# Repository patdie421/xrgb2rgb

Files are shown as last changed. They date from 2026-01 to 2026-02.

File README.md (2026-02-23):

# Goal of this converter
This card convert TTL RGB (xRGB / TTLLS / ... from some Apple IIe cards or Apple ///) to "standard" RGB. Color are not exactly the same as the Apple IIe color palette but it's usable !  
It was designed for my Taxan Model 410-80 card to chaine it with a PCT Colorswitch (see https://github.com/patdie421/pct-connectors-rebuild/blob/main/README.md).  
It should work for other kind of card who can be connected to Taxan RGBvision (mode II), AppleColour (AppleColor) 100 monitor or equivalent.  
The converter is base on the output stage circuit of the Chat Mauve EVE Card (https://mirrors.apple2.org.za/ftp.apple.asimov.net/documentation/hardware/video/Le%20Chat%20Mauve%20-%20Manuel%20de%20re_25cc_2581fe_25cc_2581rence.pdf).  
# Working status
- Apple II GS Color monitor direct connexion: tested, working
- Apple II GS Color monitor via PCT Colorswitch: tested, working
- Scart TV/Monitor: not tester (use at your own risk ... like all usual :-) )
- Other RGB monitor: can't be tested (but will be done), I have only an Apple II GS monitor ... (give me feedback, please)  
# usefull link
- https://hobbytronics.home.blog/2024/12/21/apple-iigs-rgb-monitor-scart-cable/
- https://apple3.org/Documents/Schematics/ConsortiRGB.png
- https://mirrors.apple2.org.za/ftp.apple.asimov.net/documentation/hardware/video/AppleService%20Technical%20Procedures%20-%20AppleColor%20Monitor%20100.pdf

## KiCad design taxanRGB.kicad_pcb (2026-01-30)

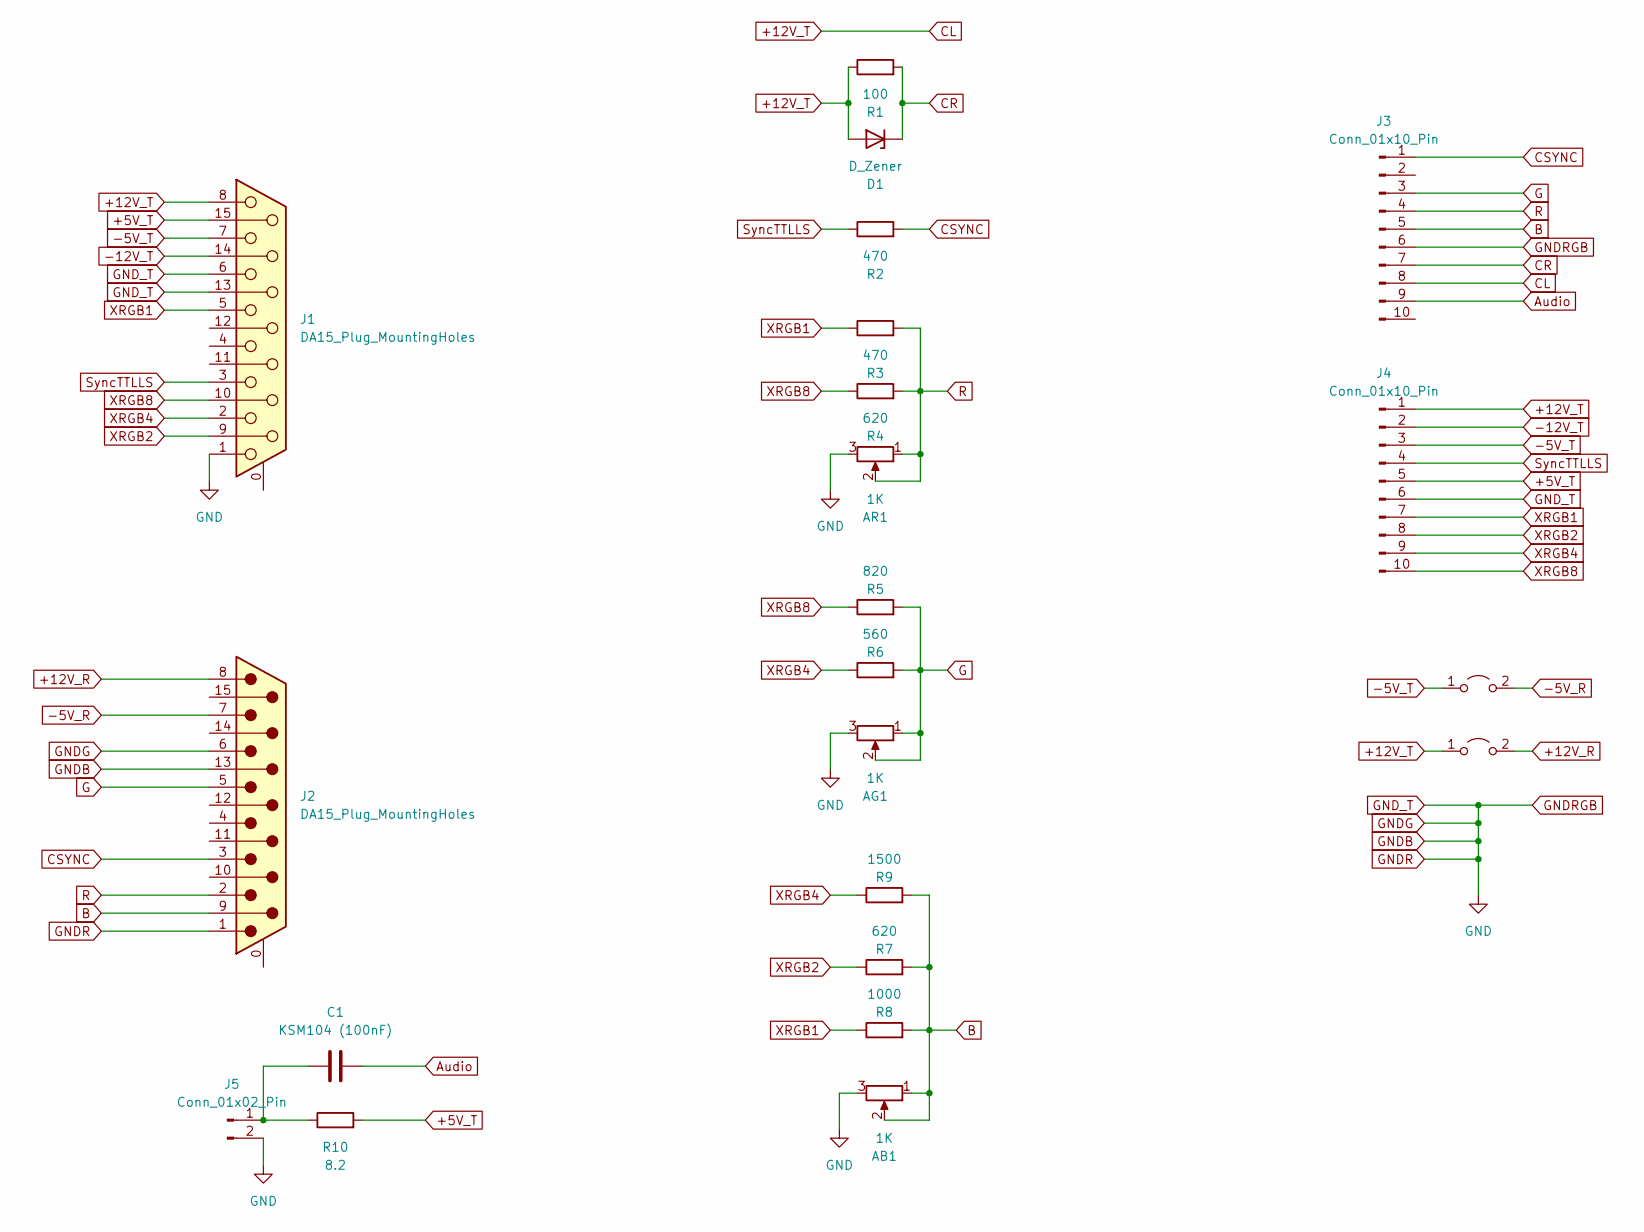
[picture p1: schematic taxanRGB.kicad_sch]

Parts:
AB1: 1K; Potentiometer_Piher_PT-10-V10_Vertical
AG1: 1K; Potentiometer_Piher_PT-10-V10_Vertical
AR1: 1K; Potentiometer_Piher_PT-10-V10_Vertical
C1: KSM104 (100nF); C_Disc_D4.3mm_W1.9mm_P5.00mm
D1: D_Zener; D_DO-34_SOD68_P10.16mm_Horizontal
J1: DA15_Plug_MountingHoles; DSUB-15_Male_EdgeMount_P2.77mm
J2: DA15_Plug_MountingHoles; DSUB-15_Female_EdgeMount_P2.77mm
J3, J4: Conn_01x10_Pin; PinHeader_1x10_P2.54mm_Vertical
J5: Conn_01x02_Pin; PinHeader_1x02_P2.54mm_Vertical
JP1, JP2: Jumper_2_Open; SolderJumper-2_P1.3mm_Open_TrianglePad1.0x1.5mm
R1: 100; R_Axial_DIN0309_L9.0mm_D3.2mm_P12.70mm_Horizontal
R2, R3: 470; R_Axial_DIN0309_L9.0mm_D3.2mm_P12.70mm_Horizontal
R4, R7: 620; R_Axial_DIN0309_L9.0mm_D3.2mm_P12.70mm_Horizontal
R5: 820; R_Axial_DIN0309_L9.0mm_D3.2mm_P12.70mm_Horizontal
R6: 560; R_Axial_DIN0309_L9.0mm_D3.2mm_P12.70mm_Horizontal
R8: 1000; R_Axial_DIN0309_L9.0mm_D3.2mm_P12.70mm_Horizontal
R9: 1500; R_Axial_DIN0309_L9.0mm_D3.2mm_P12.70mm_Horizontal
R10: 8.2; R_Axial_DIN0309_L9.0mm_D3.2mm_P12.70mm_Horizontal

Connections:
+5V_T: J1.15, J4.5, R10.2
+12V_R: J2.8, JP2.2 (B)
+12V_T: D1.2 (A), J1.8, J3.8, J4.1, JP2.1 (A), R1.1
-5V_R: J2.7, JP1.2 (B)
-5V_T: J1.7, J4.3, JP1.1 (A)
-12V_T: J1.14, J4.2
Audio: C1.1, J3.9
B: AB1.1, AB1.2, J2.9, J3.5, R7.2, R8.2, R9.2
CR: D1.1 (K), J3.7, R1.2
CSYNC: J2.3, J3.1, R2.2
G: AG1.1, AG1.2, J2.5, J3.3, R5.2, R6.2
GNDB: AB1.3, AG1.3, AR1.3, J1.1, J1.6, J1.13, J2.1, J2.6, J2.13, J3.6, J4.6, J5.2
unnamed: C1.2, J5.1, R10.1
R: AR1.1, AR1.2, J2.2, J3.4, R3.2, R4.2
SyncTTLLS: J1.3, J4.4, R2.1
XRGB1: J1.5, J4.7, R3.1, R8.1
XRGB2: J1.9, J4.8, R7.1
XRGB4: J1.2, J4.9, R6.1, R9.1
XRGB8: J1.10, J4.10, R4.1, R5.1

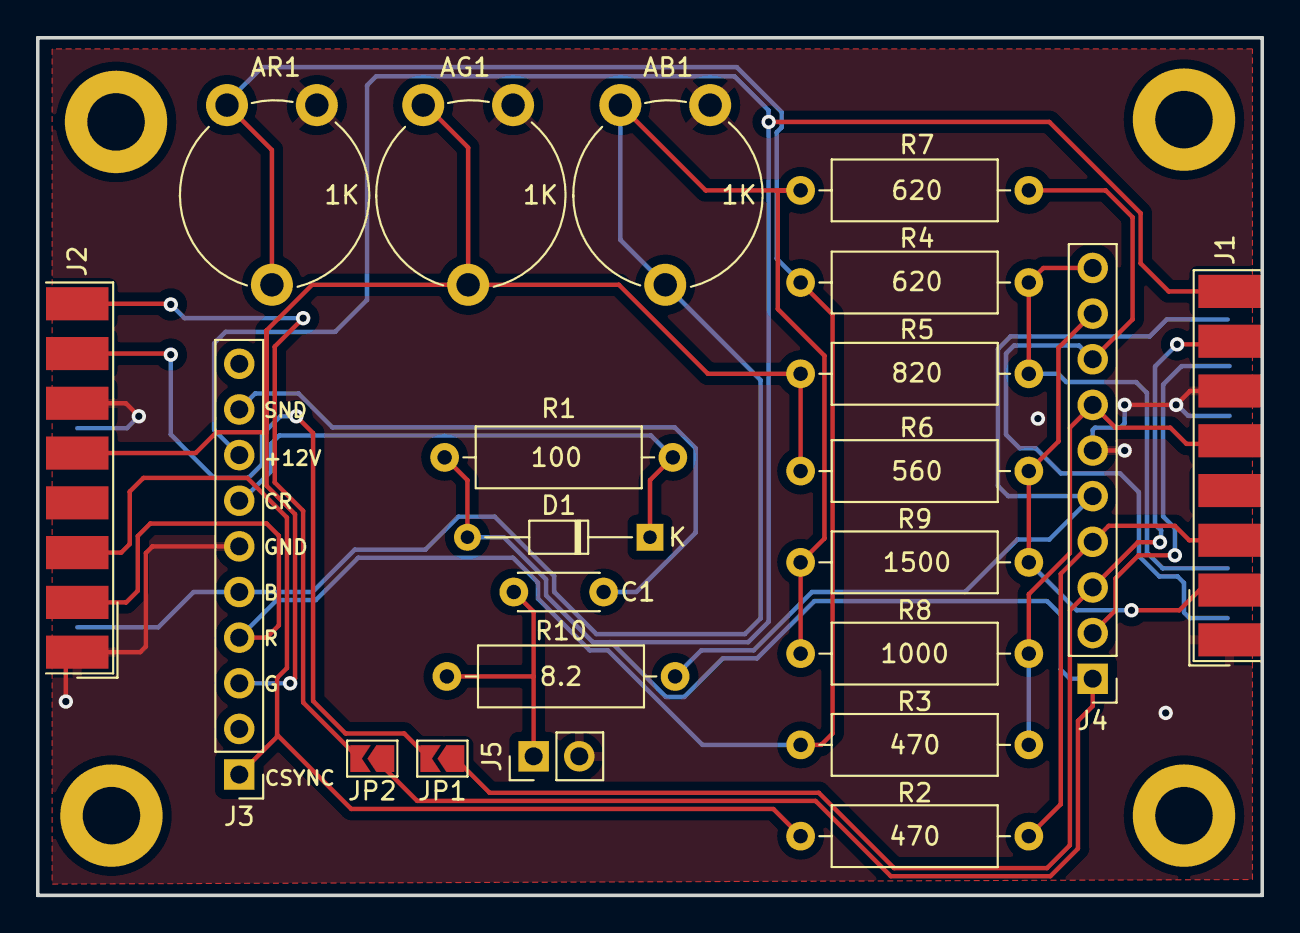
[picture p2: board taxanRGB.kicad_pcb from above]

Board: 2 copper layers, 68.2 x 47.7 mm, 22 parts (0 on the bottom side), 19 nets.
